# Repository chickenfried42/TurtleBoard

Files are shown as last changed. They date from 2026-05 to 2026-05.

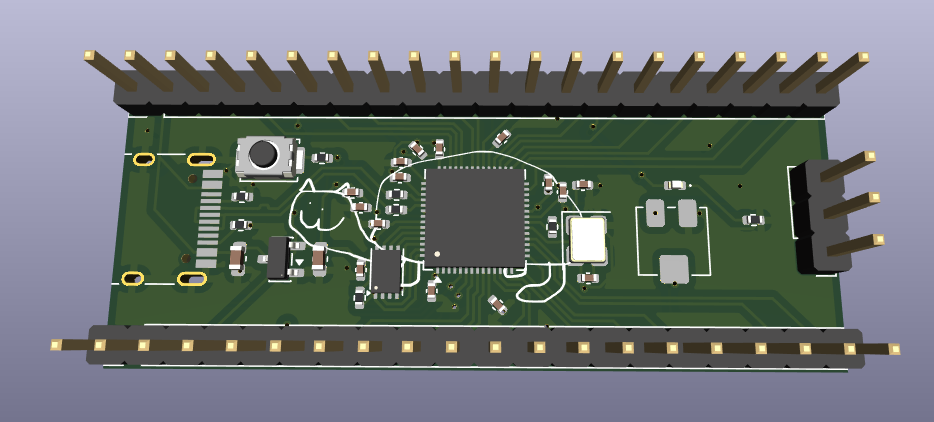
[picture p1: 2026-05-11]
Pictures/render.png

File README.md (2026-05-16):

# TurtleBoard
The TurtleBoard is a development board based on the RP2040 chip. It features 43 pins, including most standard GPIO pins, an onboard potentiometer, and LED.<br>
I made this board to learn PCB design and to understand the inner workings of dev boards. This was hell to figure out for the first time, but insanely rewarding and probably more educational than anything I ever did at school. 
Front:

Back:

Sadly, the back has no silly drawing, which is because my KiCad kept crashing whenever I tried doing anything with it, so I left it alone out of fear of corrupting the design file or something.

# Schematic


# PCB
pcb


# JLCPCB Render


# BOM
|Reference |Quantity|Comment |Total Cost|Part #|Exclude from Board|Footprint |Datasheet |
|---|---|---|---|---|---|---|---|
|C1,C10 |2 |1uF |$0.04|CL05A105KA5NQNC| |Capacitor_SMD:C_0402_1005Metric |~ |
|C2,C3,C4,C5,C6,C7,C8,C9,C11,C12,C17|10 |0.1uF |$0.0825|CL05B104KO5NNNC| |Capacitor_SMD:C_0402_1005Metric |~ |
|C13,C14 |2 |10uF |$0.102|CL10A106KP8NNNC| |Capacitor_SMD:C_0603_1608Metric |~ |
|C15,C16 |2 |33pF |$0.013|0402CG330J500NT| |Capacitor_SMD:C_0402_1005Metric |~ |
|D1 |1 |LED |$0.332|16-213SDRC/S530-A3/TR8| |LED_SMD:LED_0402_1005Metric |~ |
|J1 |1 |USB_C_Receptacle_USB2.0_14P|$0.918|TYPE-C-31-M-12| |Connector_USB:USB_C_Receptacle_HRO_TYPE-C-31-M-12 |https://www.usb.org/sites/default/files/documents/usb_type-c.zip |
|J2,J3 |2 |Conn_01x20 |$1.36 |2.54-1*20P直针| |Connector_PinHeader_2.54mm:PinHeader_1x20_P2.54mm_Vertical|~ |
|J4 |1 |Conn_01x03 |$0.2488|1.27-1*3P针| |Connector_PinHeader_2.54mm:PinHeader_1x03_P2.54mm_Vertical|~ |
|R1,R2 |2 |5.1K |$0.009|0402WGF5101TCE| |Resistor_SMD:R_0402_1005Metric |~ |
|R3,R4 |2 |27 |$0.0176|0402WGF270JTCE| |Resistor_SMD:R_0402_1005Metric |~ |
|R5,R7 |2 |1K |$0.01|0402WGF1001TCE| |Resistor_SMD:R_0402_1005Metric |~ |
|R6 |1 |10K |$0.0065|0402WGF1002TCE| |Resistor_SMD:R_0402_1005Metric |~ |
|R9 |1 |220 |$0.0045|0402WGF2200TCE| |Resistor_SMD:R_0402_1005Metric |~ |
|RV1 |1 |R_Potentiometer |$13.544 |3214J-1-503E| |Potentiometer_SMD:Potentiometer_Bourns_3214J_Horizontal |~ |
|SW1 |1 |SW_Push |$0.028|TS-1088-AR02016| |Button_Switch_SMD:SW_Push_SPST_NO_Alps_SKRK |~ |
|U1 |1 |RP2040 |$4.8940|RP2040| |Package_DFN_QFN:QFN-56-1EP_7x7mm_P0.4mm_EP3.2x3.2mm |https://datasheets.raspberrypi.com/rp2040/rp2040-datasheet.pdf |
|U2 |1 |MCP1700x-330xxTT |$2.398|MCP1700T-3302E/TT| |Package_TO_SOT_SMD:SOT-23 |http://ww1.microchip.com/downloads/en/DeviceDoc/20001826D.pdf |
|U3 |1 |W25Q16JVZPIQ TR |$8.0815|W25Q16JVUXIQ| |Package_SON:Winbond_USON-8-1EP_3x2mm_P0.5mm_EP0.2x1.6mm |https://www.winbond.com/resource-files/w25q128jv_dtr%20revc%2003272018%20plus.pdf|
|Y1 |1 |12MHz |$0.368|X322512MSB4SI| |Crystal:Crystal_SMD_3225-4Pin_3.2x2.5mm |~ |

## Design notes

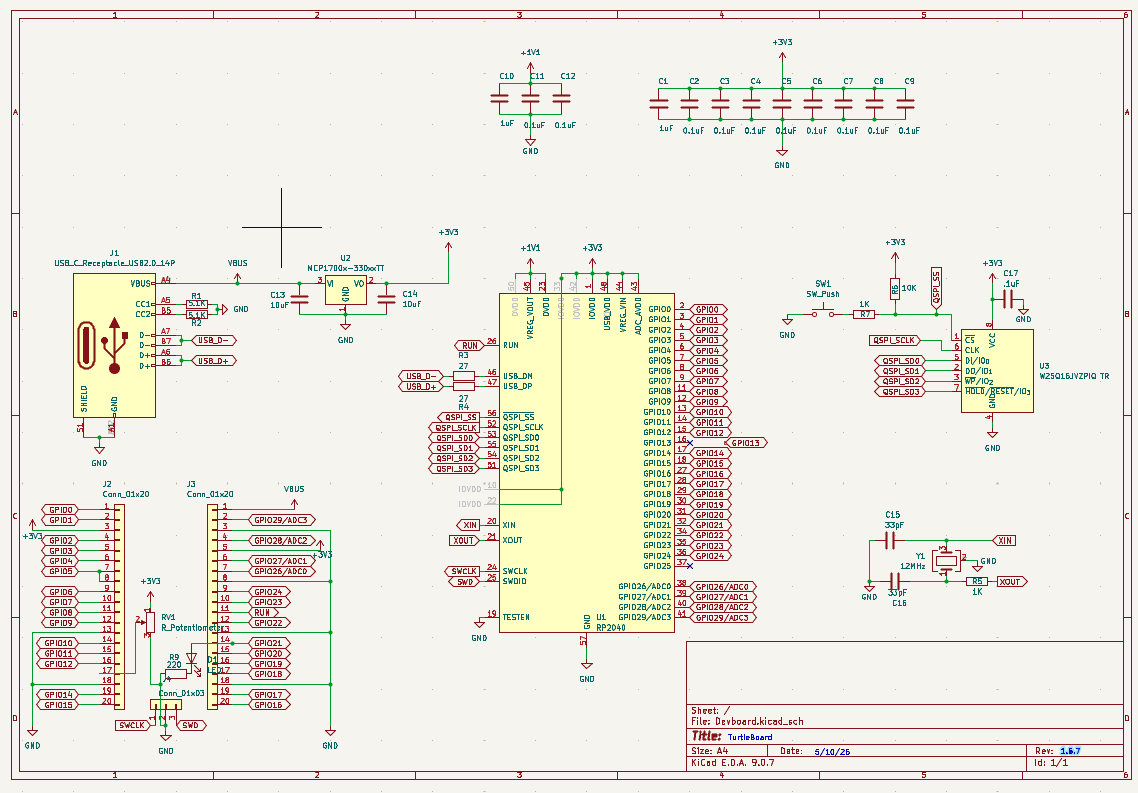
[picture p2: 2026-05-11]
schematic.png

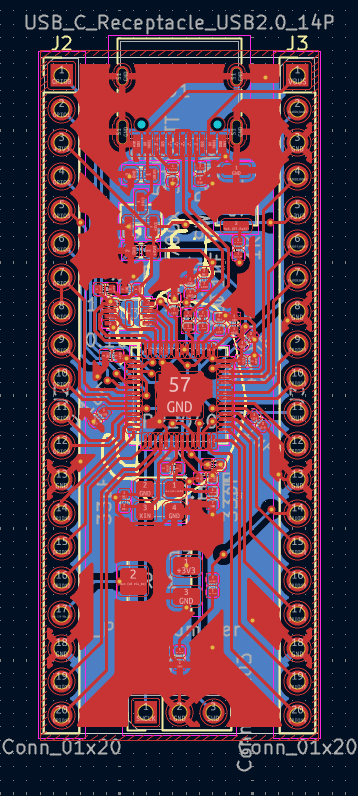
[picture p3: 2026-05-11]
Pictures/pcb.png

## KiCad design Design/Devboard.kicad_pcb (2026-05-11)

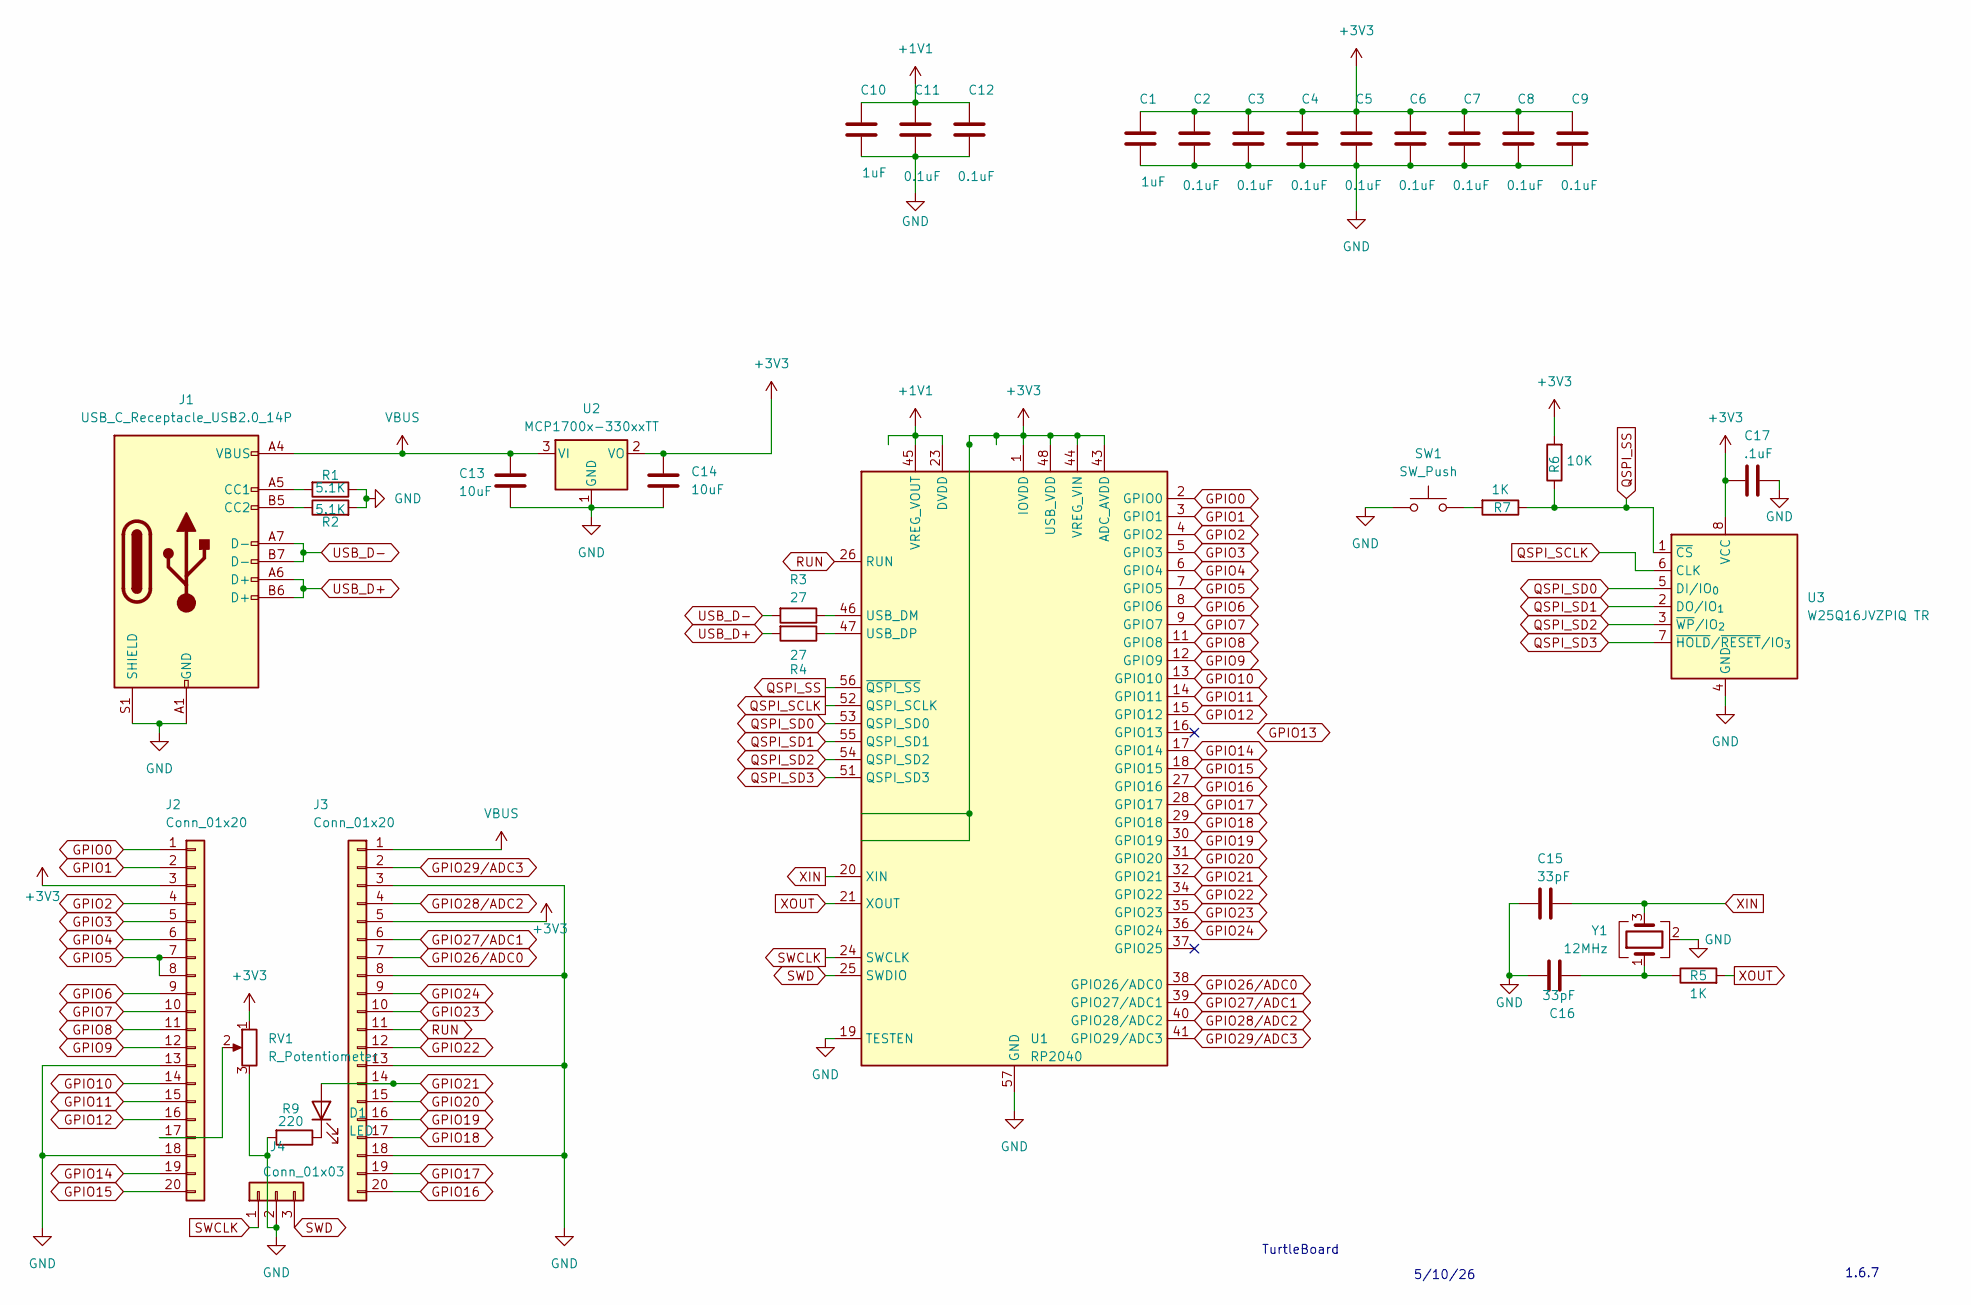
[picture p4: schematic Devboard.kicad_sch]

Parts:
C1, C10: 1uF; C_0402_1005Metric
C2, C3, C4, C5, C6, C7, C8, C9, C11, C12: 0.1uF; C_0402_1005Metric
C13, C14: 10uF; C_0603_1608Metric
C15, C16: 33pF; C_0402_1005Metric
C17: .1uF; C_0402_1005Metric
D1: LED; LED_0402_1005Metric
J1: USB_C_Receptacle_USB2.0_14P; USB_C_Receptacle_HRO_TYPE-C-31-M-12
J2, J3: Conn_01x20; PinHeader_1x20_P2.54mm_Vertical
J4: Conn_01x03; PinHeader_1x03_P2.54mm_Vertical
R1, R2: 5.1K; R_0402_1005Metric
R3, R4: 27; R_0402_1005Metric
R5, R7: 1K; R_0402_1005Metric
R6: 10K; R_0402_1005Metric
R9: 220; R_0402_1005Metric
RV1: R_Potentiometer; Potentiometer_Bourns_3214J_Horizontal
SW1: SW_Push; SW_Push_SPST_NO_Alps_SKRK
U1: RP2040; QFN-56-1EP_7x7mm_P0.4mm_EP3.2x3.2mm
U2: MCP1700x-330xxTT; SOT-23
U3: W25Q16JVZPIQ TR; Winbond_USON-8-1EP_3x2mm_P0.5mm_EP0.2x1.6mm
Y1: 12MHz; Crystal_SMD_3225-4Pin_3.2x2.5mm

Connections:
+1V1: C10.1, C11.1, C12.1, U1.23 (DVDD), U1.45 (VREG_VOUT), U1.50 (DVDD)
+3V3: C1.1, C2.1, C3.1, C4.1, C5.1, C6.1, C7.1, C8.1, C9.1, C14.1, C17.1, J2.3, J3.5, R6.2, RV1.1, U1.1 (IOVDD), U1.10 (IOVDD), U1.22 (IOVDD), U1.33 (IOVDD), U1.42 (IOVDD), U1.43 (ADC_AVDD), U1.44 (VREG_VIN), U1.48 (USB_VDD), U1.49 (IOVDD), U2.2 (VO), U3.8 (VCC)
GND: C1.2, C2.2, C3.2, C4.2, C5.2, C6.2, C7.2, C8.2, C9.2, C10.2, C11.2, C12.2, C13.2, C14.2, C15.1, C16.2, C17.2, J1.A1 (GND), J1.A12 (GND), J1.B1 (GND), J1.B12 (GND), J1.S1 (SHIELD), J2.13, J2.18, J3.3, J3.8, J3.13, J3.18, J4.2, R1.1, R2.2, R9.2, RV1.3, SW1.1, U1.19 (TESTEN), U1.57 (GND), U2.1 (GND), U3.4 (GND), Y1.2 (G), Y1.4 (G)
GPIO0: J2.1, U1.2 (GPIO0)
GPIO1: J2.2, U1.3 (GPIO1)
GPIO2: J2.4, U1.4 (GPIO2)
GPIO3: J2.5, U1.5 (GPIO3)
GPIO4: J2.6, U1.6 (GPIO4)
GPIO5: J2.7, J2.8, U1.7 (GPIO5)
GPIO6: J2.9, U1.8 (GPIO6)
GPIO7: J2.10, U1.9 (GPIO7)
GPIO8: J2.11, U1.11 (GPIO8)
GPIO9: J2.12, U1.12 (GPIO9)
GPIO10: J2.14, U1.13 (GPIO10)
GPIO11: J2.15, U1.14 (GPIO11)
GPIO12: J2.16, U1.15 (GPIO12)
GPIO14: J2.19, U1.17 (GPIO14)
GPIO15: J2.20, U1.18 (GPIO15)
GPIO16: J3.20, U1.27 (GPIO16)
GPIO17: J3.19, U1.28 (GPIO17)
GPIO18: J3.17, U1.29 (GPIO18)
GPIO19: J3.16, U1.30 (GPIO19)
GPIO20: J3.15, U1.31 (GPIO20)
GPIO21: D1.2 (A), J3.14, U1.32 (GPIO21)
GPIO22: J3.12, U1.34 (GPIO22)
GPIO23: J3.10, U1.35 (GPIO23)
GPIO24: J3.9, U1.36 (GPIO24)
GPIO26/ADC0: J3.7, U1.38 (GPIO26/ADC0)
GPIO27/ADC1: J3.6, U1.39 (GPIO27/ADC1)
GPIO28/ADC2: J3.4, U1.40 (GPIO28/ADC2)
GPIO29/ADC3: J3.2, U1.41 (GPIO29/ADC3)
unnamed: C16.1, R5.1, Y1.1
unnamed: D1.1 (K), R9.1
unnamed: J1.A5 (CC1), R1.2
unnamed: J1.B5 (CC2), R2.1
unnamed: J2.17, RV1.2
unnamed: R7.2, SW1.2
unnamed: R3.1, U1.46 (USB_DM)
unnamed: R4.1, U1.47 (USB_DP)
QSPI_SCLK: U1.52 (QSPI_SCLK), U3.6 (CLK)
QSPI_SD0: U1.53 (QSPI_SD0), U3.5 (DI/IO_{0})
QSPI_SD1: U1.55 (QSPI_SD1), U3.2 (DO/IO_{1})
QSPI_SD2: U1.54 (QSPI_SD2), U3.3 (~WP/IO_{2})
QSPI_SD3: U1.51 (QSPI_SD3), U3.7 (~HOLD/~RESET/IO_{3})
QSPI_SS: R6.1, R7.1, U1.56 (~QSPI_SS), U3.1 (~CS)
RUN: J3.11, U1.26 (RUN)
SWCLK: J4.1, U1.24 (SWCLK)
SWD: J4.3, U1.25 (SWDIO)
USB_D+: J1.A6 (D+), J1.B6 (D+), R4.2
USB_D-: J1.A7 (D-), J1.B7 (D-), R3.2
VBUS: C13.1, J1.A4 (VBUS), J1.A9 (VBUS), J1.B4 (VBUS), J1.B9 (VBUS), J3.1, U2.3 (VI)
XIN: C15.2, U1.20 (XIN), Y1.3
XOUT: R5.2, U1.21 (XOUT)

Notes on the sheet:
5/10/26
TurtleBoard
1.6.7

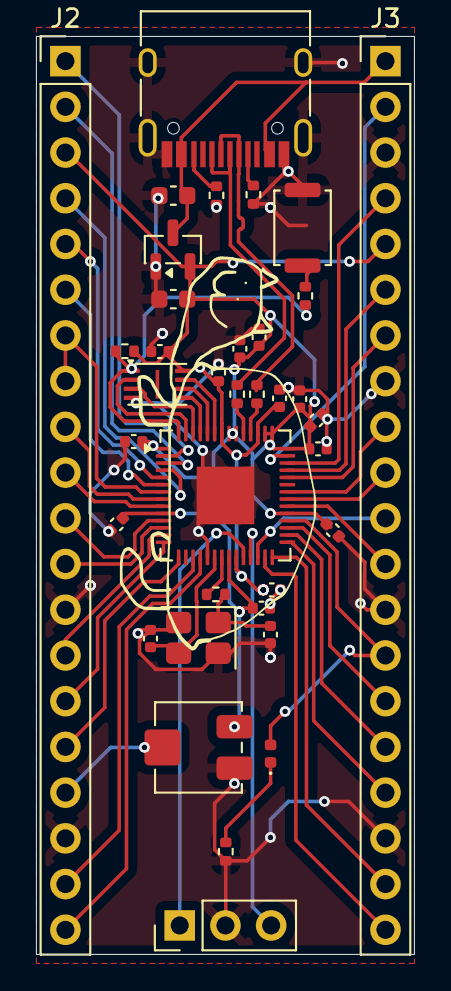
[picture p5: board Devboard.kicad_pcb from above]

Board: 2 copper layers, 21.0 x 51.0 mm, 36 parts (0 on the bottom side), 53 nets.

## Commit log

2026-05-11 added files
    stuff
    [BOM.csv, Devboard.kicad_pcb, Devboard.kicad_sch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]
2026-05-16 fixed bom
    ya
    [BOM.csv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]
